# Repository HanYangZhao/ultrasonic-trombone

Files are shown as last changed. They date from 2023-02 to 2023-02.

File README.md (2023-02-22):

# A DIY contoller for Trombone Champ

This controller is made using an ultrasonic sensor, Teensy, a button, three 3D printed parts and 2 pieces of 1 inch PVC tubing. It emulates mouse emulation based on the distance between the ultrasonic sensor and the sliding piece. Unlike the controller that are based on potentiometer, this one offers very low friction just like a real trombone. A button is used to simulate the blowing action.

Demo : 
https://www.youtube.com/watch?v=xJ7Nz3pXyhk

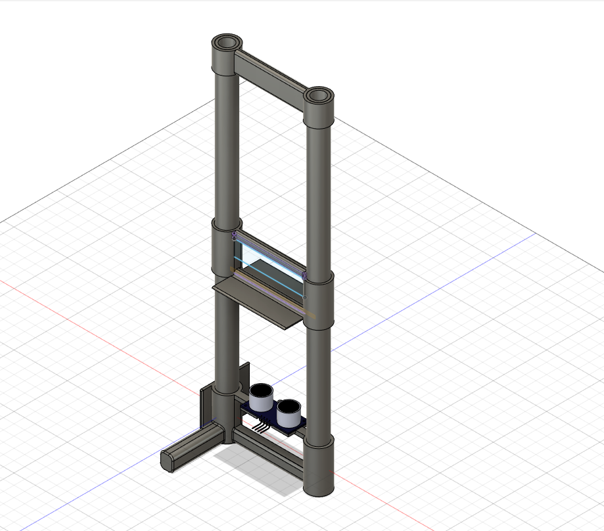
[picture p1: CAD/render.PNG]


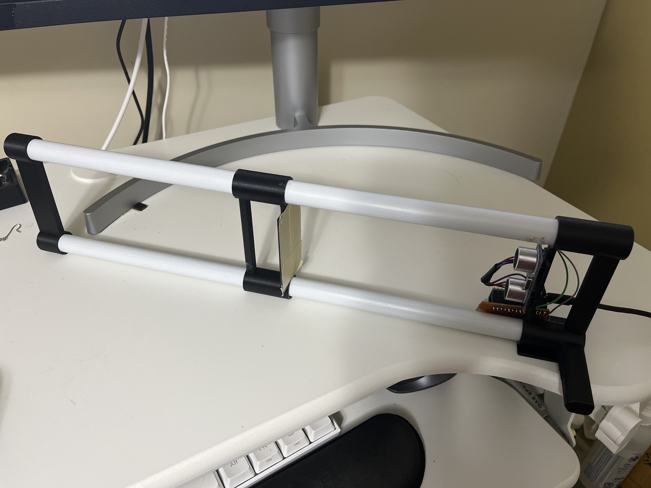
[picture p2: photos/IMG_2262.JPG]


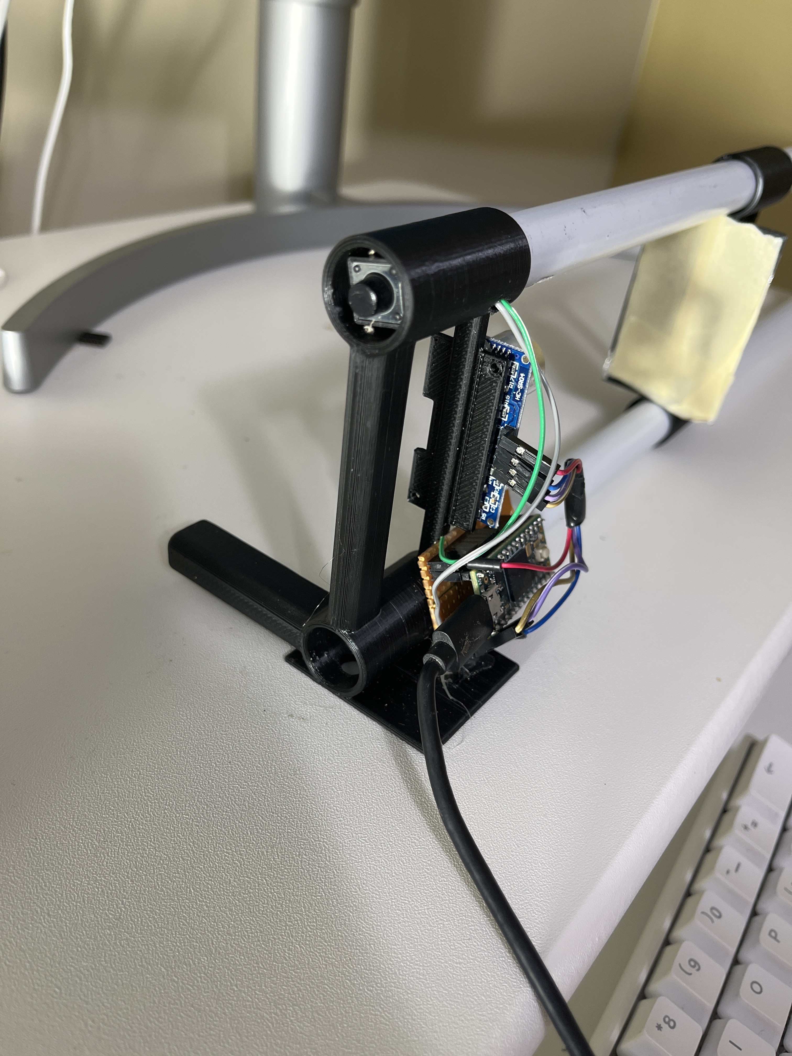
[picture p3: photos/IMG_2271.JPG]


# Part List
* 1 x Teensy 4.0 (3.2 should work as well)
* 1 x Ultrasonic Sensor HC-SR04 or equivalent
* 1 x Button
* 1 x Perforated PCB board
* 2 x 40 CM PVC tubing (0.58 inch / 15.8mm OD )
* 3 x 3D printed parts

# Wiring

## Ultrasonic Sensor

```
VCC     ----> 5V
trigPin ----> PIN 1
echoPin ----> PIN 0
GND     ----> GND
```

## Button 
```
MOUSE_LEFTCLICK_PIN ----> PIN 23
```

## Code
The original code was downloaded somewhere on the Internet and modified by me, but I was unable to locate it. Credit goes to whoever made that original code.

The current code use Mouse.move() because Mouse.moveTo() does not work in Linux/Mac. By using Mouse.move() we can use this on a Steam Deck
https://www.pjrc.com/teensy/td_mouse.html

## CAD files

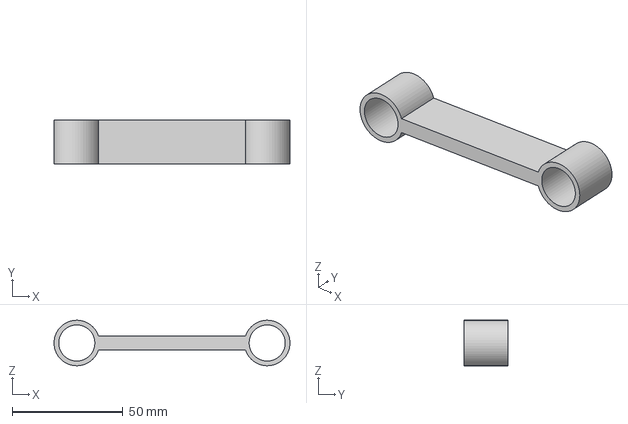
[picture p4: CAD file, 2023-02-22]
CAD/front_holder.stp
106.6 x 20.0 x 20.6 mm

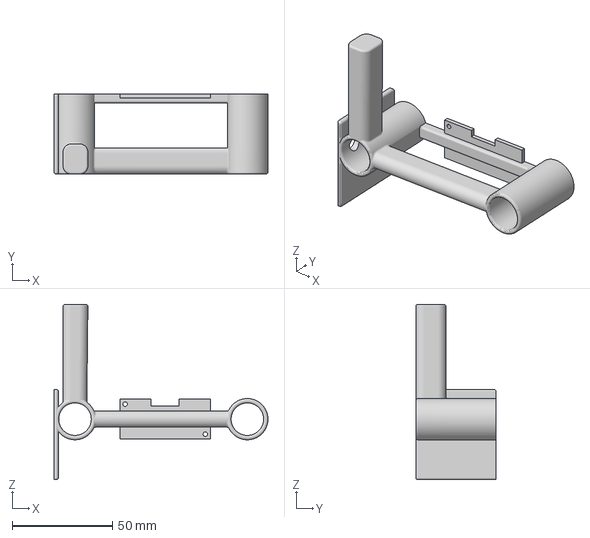
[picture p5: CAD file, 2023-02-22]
CAD/back_holder.3mf
106.8 x 40.0 x 87.5 mm

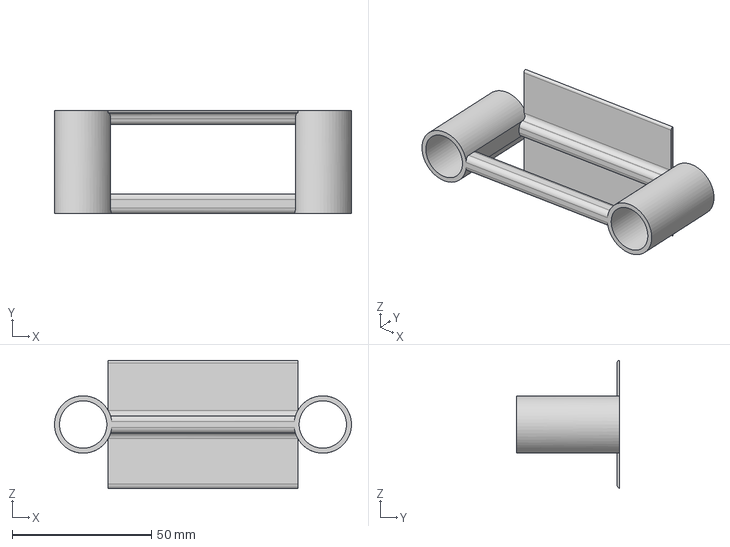
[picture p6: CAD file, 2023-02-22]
CAD/slider.stp
106.6 x 37.0 x 46.1 mm

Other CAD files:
CAD/front_holder.3mf
CAD/slider.3mf

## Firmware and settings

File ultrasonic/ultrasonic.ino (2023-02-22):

#include <Bounce2.h>
#define PIN_MIC A8
#define MOUSE_LEFTCLICK_PIN 23
// SETTINGS
#define p_trigPin_cadangan  1
#define p_echoPin_cadangan  0
#define SCREEN_WIDTH 1920   // Doesn't have to be exact;
#define SCREEN_HEIGHT 1080  // probably just the ratio.
#define SLIDE_MAX_MM 300
#define TOOT_THRESHOLD 200
#define DELAY 1
#define AVG_TOOT_COUNT 15
// GLOBALS
int toots[AVG_TOOT_COUNT]; // to hold the running average
int mouse_y = 0;
int avg_dist_mm = 0;
float dist_cm = 0;
int current_dist_mm = 0;
int previous_dist_mm = 0;
elapsedMillis currentTime;
float curerntSpeed = 0;
float previousSpeed = 0;
int previousTime = 0;
float elapsedTimeMS = 0;
Bounce2::Button mouse_button = Bounce2::Button();
int initial_mic_level = 0;
void us_setup()
{
  pinMode(p_trigPin_cadangan, OUTPUT);
  pinMode(p_echoPin_cadangan, INPUT);
}
float us_get_jarak(int triger, int echo)
{
  long duration;
  float distance;
  int i;

  digitalWrite(triger, LOW);
  delayMicroseconds(2);
  digitalWrite(triger, HIGH);
  delayMicroseconds(10);
  digitalWrite(triger, LOW);
  duration =  pulseIn(echo, HIGH,10000); //uS

  distance = duration * 0.034 / 2; //mm

  return distance;
}

//--------------------------------#MY AVERAGE
#define n_my_data 10
float my_data[n_my_data];
int i_my_data = 0;

float my_moving_average(float in_data, int debug)
{
  float my_ave;
  float my_sum;

  my_data[i_my_data] = in_data;

  if (my_data[n_my_data - 1] == 0)
  {
    my_sum = 0;

    for (int i = 0; i <= i_my_data; i++)
    {
      my_sum += my_data[i];
    }
    my_ave = my_sum / (i_my_data + 1);
  }
  else
  {
    my_sum = 0;
    for (int i = 0; i < n_my_data; i++)
    {
      my_sum += my_data[i];
    }
    my_ave = my_sum / n_my_data;
  }


  //#Debug
  if (debug)
  {
    for (int i = 0; i < n_my_data; i++)
    {
      Serial.print(i); Serial.print(" "); Serial.println(my_data[i]);
    }
    Serial.print("i"); Serial.print(" "); Serial.println(i_my_data);
    Serial.print("Last"); Serial.print(" "); Serial.println(my_data[n_my_data - 1]);

    Serial.print("Sum"); Serial.print(" "); Serial.println(my_sum);
    Serial.print("Ave"); Serial.print(" "); Serial.println(my_ave);
    Serial.println();
  }



  i_my_data++;
  if (i_my_data >= n_my_data)
    i_my_data = 0;

  return my_ave;
}

void my_moving_ave_clear()
{
  //Make sure All Array is 0
  for (int i = 0; i < n_my_data; i++)
  {
    my_data[i] = 0;
  }
}

int smoothJazz(int toot) {
  static int averageToot = 0;
  static int readIndex = 0;              // the index of the current reading
  static int total = 0;                  // the running total
  // subtract the last reading:
  total = total - toots[readIndex];
  // read from the sensor:
  toots[readIndex] = toot;
  // add the reading to the total:
  total = total + toots[readIndex];
  // advance to the next position in the array:
  readIndex = readIndex + 1;
  // if we're at the end of the array...
  if (readIndex >= AVG_TOOT_COUNT) {
    // ...wrap around to the beginning:
    readIndex = 0;
  }
  // calculate the average:
  return total / AVG_TOOT_COUNT;
}

void turdAverage() {
  for (int r = 0; r < TOOT_THRESHOLD; r++) {
    toots[r] = 0;
  }
}

void tootTromboneBlow(int toot) {
  static bool blowing = false;
  if (toot > TOOT_THRESHOLD) {
    if (!blowing) {
      Mouse.set_buttons(1, 0, 0);
    }
    blowing = true;
  } else {
    if (blowing) {
      Mouse.set_buttons(0, 0, 0);
      turdAverage();
    }
    blowing = false;
  }
}

void tootTromboneClick() {
  mouse_button.update(); // Update the Bounce instance
  if (mouse_button.isPressed()){
    Mouse.set_buttons(1, 0, 0);
  } else {
    Mouse.set_buttons(0, 0, 0);
  }
}

void setup() {
  Serial.begin(9600);
  Mouse.screenSize(SCREEN_WIDTH, SCREEN_HEIGHT);
  us_setup();
  my_moving_ave_clear();
  mouse_button.attach(MOUSE_LEFTCLICK_PIN, INPUT_PULLUP);
  mouse_button.interval(10);
  mouse_button.setPressedState(LOW);
  previous_dist_mm = us_get_jarak(p_trigPin_cadangan, p_echoPin_cadangan) * 10;
  previousTime = currentTime;
}

void loop()
{
  tootTromboneClick();
//  tootTromboneBlow(smoothJazz(analogRead(PIN_MIC)));
//  initial_mic_level = analogRead(PIN_MIC);
//  Serial.println(smoothJazz(analogRead(PIN_MIC) - initial_mic_level));
  
  dist_cm =  us_get_jarak(p_trigPin_cadangan, p_echoPin_cadangan);
  avg_dist_mm = my_moving_average(dist_cm, 0) * 10;
  elapsedTimeMS =  float(currentTime - previousTime );
  previousTime = currentTime;
  float currentSpeed = float(avg_dist_mm - previous_dist_mm) / float(elapsedTimeMS); // mm/ms
  previousSpeed = currentSpeed;
  mouse_y = ((avg_dist_mm - previous_dist_mm) / elapsedTimeMS ) * -15;
  previous_dist_mm = avg_dist_mm;
  Serial.println(mouse_y); 
  Mouse.move(500, mouse_y);
  delay(3);
}
